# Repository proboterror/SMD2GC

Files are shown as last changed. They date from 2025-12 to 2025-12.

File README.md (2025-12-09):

# Sega Mega Drive to GameCube controller adapter

Also supports Xbox controllers (Xbox 360 / One / Series) and standard USB HID gamepads (with layout similar to PS4 DualShock 4) with USB Type-C OTG adapter.

USB gamepads support can be limited because of GameCube controller port does not provide sufficient +5V power (PS5 DualSense not working).

Bluetooth dongles are not supported unless they emulate standard USB HID device.

DualShock 3 / DualShock 4 / Xbox One / Series controllers are recommended.

Tested with USB controlers:

|Model|State|
|-----|-----|
|Xbox 360 USB|Working|
|Xbox One Model 1537|Working|
|Xbox Series Model 1914|Working|
|PS3 DualShock 3 CECHZC2R|Working|
|PS4 DualShock 4 CUH-ZCT1E|Working|
|PS5 DualSense CFI-ZCT1W|Not working<br>Unsufficient power|

## Schematics

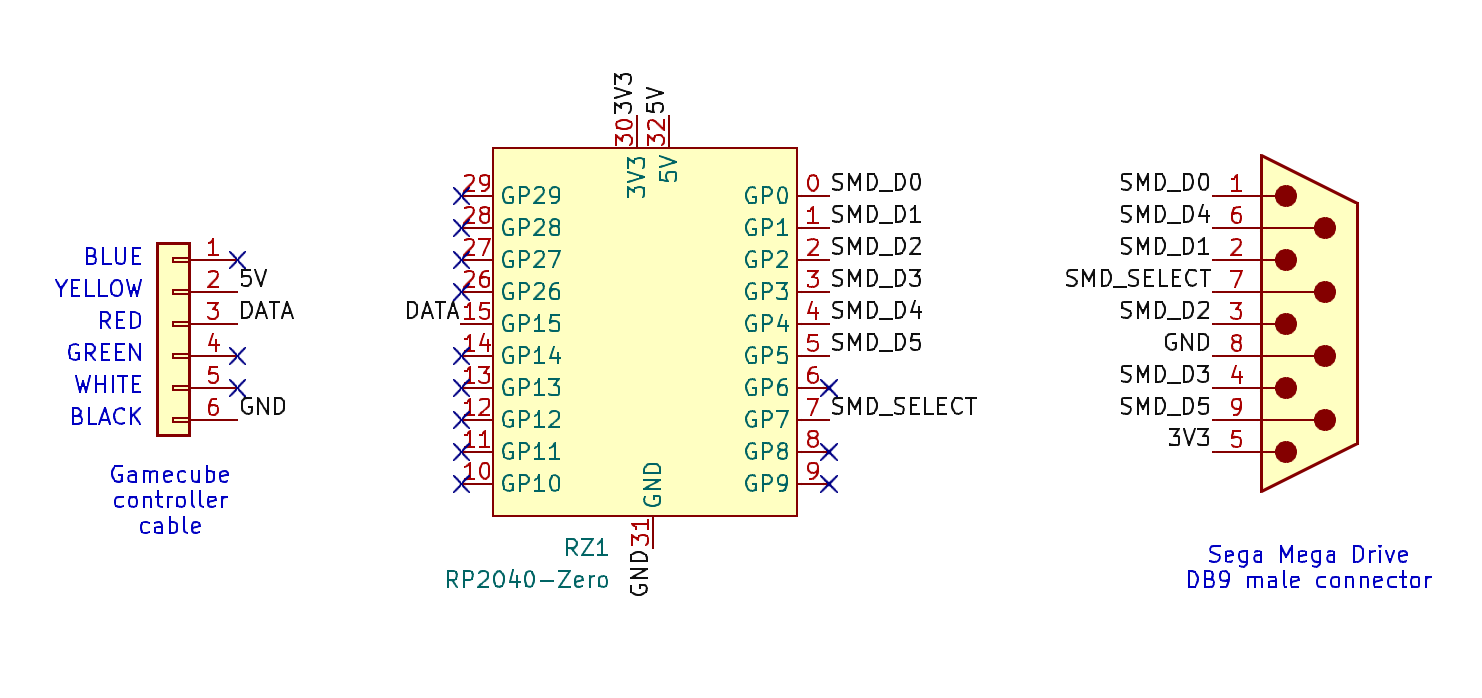
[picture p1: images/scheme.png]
Schematics


## Bill of Materials
- GameCube controller replacement cable
- WaveShare RP2040-Zero board
- DB9 Male connector
- 12 wires (approx. 60 mm each); 3 wires for USB pads only

## Buttons mapping
A/B, X/Y buttons mapping for USB gamepads matches Xbox controllers layout (reverse SNES A/B, X/Y).

### Sega Mega Drive 6-button pad
src/main.cpp:
```
gc.a = smd.a;
gc.b = smd.b;
gc.x = smd.x;
gc.y = smd.y;

gc.l = smd.z;
gc.r = smd.c;

gc.start = smd.start;

gc.dLeft = smd.left;
gc.dRight = smd.right
gc.dDown = smd.down
gc.dUp = smd.up
gc.z = smd.mode
```
### Xbox controllers
src/main.c:
```
gc.a = (buttons & XINPUT_GAMEPAD_A);
gc.b = (buttons & XINPUT_GAMEPAD_B);
gc.x = (buttons & XINPUT_GAMEPAD_X);
gc.y = (buttons & XINPUT_GAMEPAD_Y);

gc.start = (buttons & (XINPUT_GAMEPAD_START | XINPUT_GAMEPAD_GUIDE));

gc.dLeft = (buttons & XINPUT_GAMEPAD_DPAD_LEFT);
gc.dRight = (buttons & XINPUT_GAMEPAD_DPAD_RIGHT);
gc.dDown = (buttons & XINPUT_GAMEPAD_DPAD_DOWN);
gc.dUp = (buttons & XINPUT_GAMEPAD_DPAD_UP);

const uint8_t TRIGGER_CLICK_TRESHOLD = 32;
gc.l = pad->bLeftTrigger > TRIGGER_CLICK_TRESHOLD
gc.r = pad->bRightTrigger > TRIGGER_CLICK_TRESHOLD;

gc.z = (buttons & XINPUT_GAMEPAD_RIGHT_SHOULDER);

gc.xStick = int16_to_u8_biased(pad->sThumbLX);
gc.yStick = int16_to_u8_biased(pad->sThumbLY);

gc.cxStick = int16_to_u8_biased(pad->sThumbRX);
gc.cyStick = int16_to_u8_biased(pad->sThumbRY);

gc.analogL = pad->bLeftTrigger;
gc.analogR = pad->bRightTrigger;
```

### Standard USB HID controllers (DualShock 4)
src/hid_gamecube_mapping.cpp:
```
REPORT_USAGE_PAGE_BUTTON, 1, MAP_GAMECUBE_BUTTON_X // Square -> X
REPORT_USAGE_PAGE_BUTTON, 2, MAP_GAMECUBE_BUTTON_A // Cross -> A
REPORT_USAGE_PAGE_BUTTON, 3, MAP_GAMECUBE_BUTTON_B // Circle -> B
REPORT_USAGE_PAGE_BUTTON, 4, MAP_GAMECUBE_BUTTON_Y // Triangle -> Y

REPORT_USAGE_PAGE_BUTTON, 6, MAP_GAMECUBE_BUTTON_Z // R1

// Note: DualShock S4 generates press event starting from minimum force,
// GameCube controller generates L/R clicks after maximum force to analog L/R axes applied.
// Can be replaced with mapping analog Rx/Ry axis with MAP_TYPE_THRESHOLD_ABOVE 192 (75%) to GameCube L/R.
REPORT_USAGE_PAGE_BUTTON, 7, MAP_GAMECUBE_BUTTON_L // L2 Digital
REPORT_USAGE_PAGE_BUTTON, 8, MAP_GAMECUBE_BUTTON_R // R2 Digital

REPORT_USAGE_PAGE_BUTTON, 10, MAP_GAMECUBE_BUTTON_START // Options -> Start

// Left analog
REPORT_USAGE_X, MAP_GAMECUBE_AXIS_X // LX
REPORT_USAGE_Y, MAP_GAMECUBE_AXIS_Y // LY, inverted
// Right analog
REPORT_USAGE_Z, MAP_GAMECUBE_AXIS_CX // RX 
REPORT_USAGE_Rz, MAP_GAMECUBE_AXIS_CY // RY, inverted
// Analog left/right triggers
REPORT_USAGE_Rx, MAP_GAMECUBE_AXIS_L // LT / R2
REPORT_USAGE_Ry, MAP_GAMECUBE_AXIS_R // RT / R2

// POV/HAT switch (also D-PAD in most cases)
// 0 on hat switch, just press up
MAP_GAMECUBE_U, HID_GAMEPAD_HAT_UP
// 1 on hat switch, press up and right
HID_GAMEPAD_HAT_UP_RIGHT, MAP_GAMECUBE_U
HID_GAMEPAD_HAT_UP_RIGHT, MAP_GAMECUBE_R
// 2 on hat switch, press right
HID_GAMEPAD_HAT_RIGHT, MAP_GAMECUBE_R
// 3 on hat, press right and down
HID_GAMEPAD_HAT_DOWN_RIGHT, MAP_GAMECUBE_R
HID_GAMEPAD_HAT_DOWN_RIGHT, MAP_GAMECUBE_D
// 4 on hat, press down
HID_GAMEPAD_HAT_DOWN, MAP_GAMECUBE_D
// 5 on hat, press down and left
HID_GAMEPAD_HAT_DOWN_LEFT, MAP_GAMECUBE_D
HID_GAMEPAD_HAT_DOWN_LEFT, MAP_GAMECUBE_L
// 6 on hat, press left
HID_GAMEPAD_HAT_LEFT, MAP_GAMECUBE_L
// 7 on hat, press left and up
HID_GAMEPAD_HAT_UP_LEFT, MAP_GAMECUBE_L
HID_GAMEPAD_HAT_UP_LEFT, MAP_GAMECUBE_U

// Rarely used
REPORT_USAGE_DPAD_UP, MAP_GAMECUBE_U
REPORT_USAGE_DPAD_DOWN, MAP_GAMECUBE_D
REPORT_USAGE_DPAD_RIGHT, MAP_GAMECUBE_R
REPORT_USAGE_DPAD_LEFT, MAP_GAMECUBE_L

PS4 DualShock 4 / PS5 DualSense used as reference for buttons IDs:
Button 0x01 - Square button
Button 0x02 - Cross button
Button 0x03 - Circle button
Button 0x04 - Triangle button
Button 0x05 - L1 button
Button 0x06 - R1 button
Button 0x07 - L2 button
Button 0x08 - R2 button
Button 0x09 - Share button
Button 0x0A - Options button
Button 0x0B - L3 button
Button 0x0C - R3 button
Button 0x0D - PS button
Button 0x0E - Touchpad button
```

### DualShock 3
```
gc.a = ps3->button_cross;
gc.b = ps3->button_circle;
gc.x = ps3->button_square;
gc.y = ps3->button_triangle;
gc.start = ps3->button_start;

gc.dLeft = ps3->dpad_left;
gc.dRight = ps3->dpad_right;
gc.dDown = ps3->dpad_down;
gc.dUp = ps3->dpad_up;

const uint8_t TRIGGER_CLICK_TRESHOLD = 32;
gc.l = ps3->trigger_l2_analog > TRIGGER_CLICK_TRESHOLD;
gc.r = ps3->trigger_r2_analog > TRIGGER_CLICK_TRESHOLD;

gc.z = ps3->trigger_r1;

gc.xStick = ps3->joy_left_x;
gc.yStick = UINT8_MAX - ps3->joy_left_y;
gc.cxStick = ps3->joy_right_x;
gc.cyStick = UINT8_MAX - ps3->joy_right_y;
gc.analogL = ps3->trigger_l2_analog;
gc.analogR = ps3->trigger_r2_analog;
```

## Input lag / latency
For Sega Mega Drive 6 buttons pad delay mostly defined by GameCube controller JoyBus speed if queried once per frame:<br>
3 bytes console request + 8 bytes response @250kbps: protocol delay ~0.35 ms.

USB pads are reports its state at fixed rate, mostly 125Hz (8 ms latency).<br>
DualShock 4 has a default wired polling rate 250Hz (4ms latency)<br>
Xbox Series Controller Model 1914: default USB poll rate 125Hz (8 ms latency)

## How to flash firmware
- Connect RP2040-Zero to PC
- Press BOOT and then RESET, new drive will appear
- Drop SMD2GC.uf2 from Releases section to new drive

## How to build firmware
Checkhout git repository.
```
git submodule update --init
```
Easy way:
- Install Visual Studio Code and official Raspberry Pi Pico Visual Studio Code extension
- On "Raspberry Pi Pico Project" left tab: "Import project"
- "Configure Cmake", use toolchain installed with Raspberry Pi Pico Visual Studio Code extension
- "Compile Project"
- "Run Project (USB)". Board should be in BOOT mode.

Hard way:
- Install Raspberry Pi Pico SDK, ARM-GCC toolchain, CMake.

## Credits
- [Julien Bernard](https://github.com/JulienBernard3383279/pico-rectangle) - Joybus protocol (Gamecube controller) implementation for the Raspberry Pi Pico
- [riguetti](https://github.com/riguetti/RP2040-Zero-gamecube-controller) - unused code cleanup
- [Andrew Tait](https://github.com/rasteri/HIDman) - USB HID descriptors and reports parsing code
- [Ryzee119](https://github.com/Ryzee119/tusb_xinput) - Xbox/Xinpit controllers support module for TinyUSB library

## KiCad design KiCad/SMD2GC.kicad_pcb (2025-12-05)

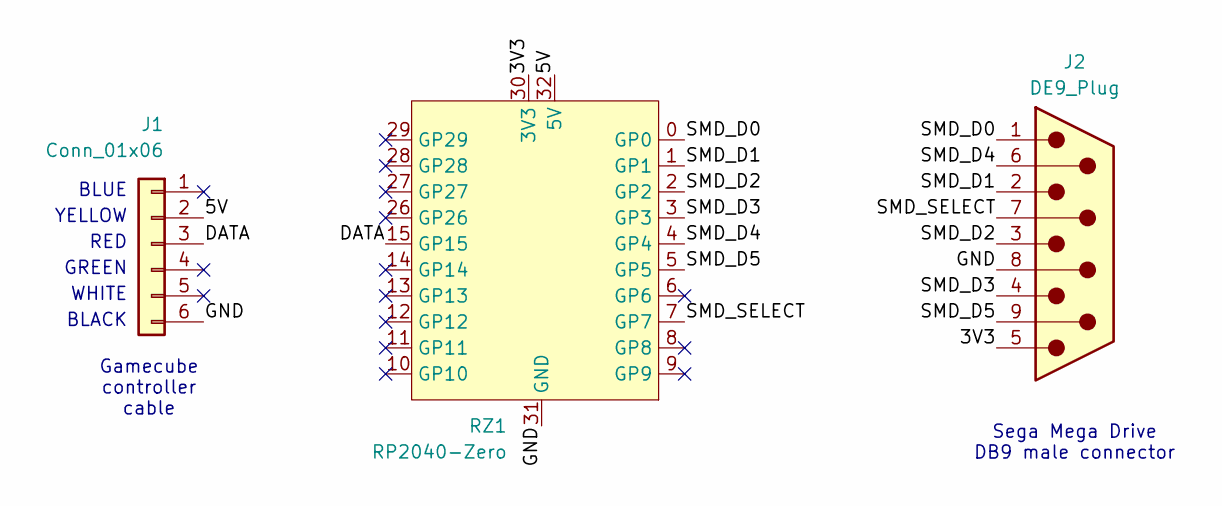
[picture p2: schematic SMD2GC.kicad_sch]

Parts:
J1: Conn_01x06; PinHeader_1x06_P2.00mm_Vertical
J2: DE9_Plug; DSUB-9_Male_Horizontal_P2.77x2.84mm_EdgePinOffset7.70mm_Hou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
RZ1: RP2040-Zero

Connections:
/3V3: J2.5, RZ1.30 (3V3)
/5V: J1.2, RZ1.32 (5V)
/DATA: J1.3, RZ1.15 (GP15)
/GND: J1.6, J2.8, RZ1.31 (GND)
/SMD_D0: J2.1, RZ1.0 (GP0)
/SMD_D1: J2.2, RZ1.1 (GP1)
/SMD_D2: J2.3, RZ1.2 (GP2)
/SMD_D3: J2.4, RZ1.3 (GP3)
/SMD_D4: J2.6, RZ1.4 (GP4)
/SMD_D5: J2.9, RZ1.5 (GP5)
/SMD_SELECT: J2.7, RZ1.7 (GP7)

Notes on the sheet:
YELLOW
WHITE
Sega Mega Drive DB9 male connector
BLUE
RED
Gamecube controller cable
BLACK
GREEN

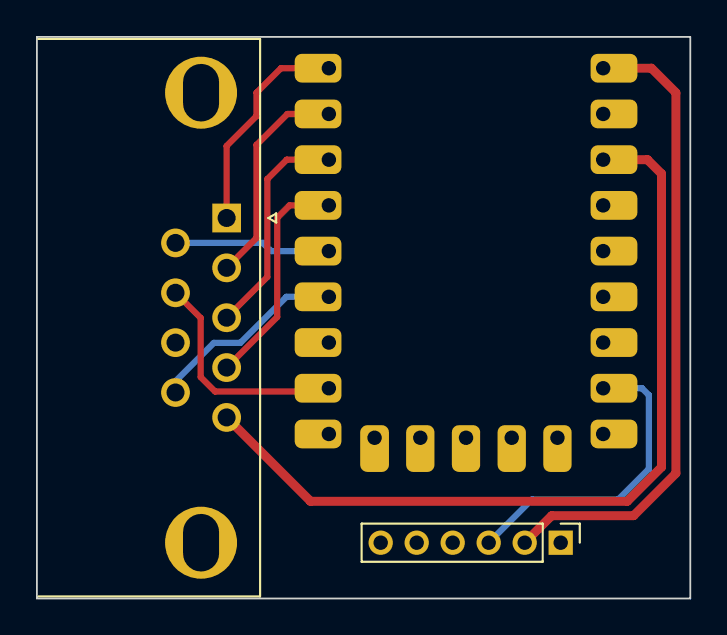
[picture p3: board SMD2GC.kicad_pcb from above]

Board: 2 copper layers, 36.3 x 31.2 mm, 3 parts (1 on the bottom side), 11 nets.

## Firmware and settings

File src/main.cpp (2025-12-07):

#include "pico/stdlib.h"
#include "pico/multicore.h"
#include "pico/sync.h"
#include "pico/stdio_uart.h"
#include "hardware/clocks.h"

#include "host/usbh.h"
#include "tusb.h"

#include "hid_parser.h"
#include "hid_gamecube_mapping.h"

#include "ps3.h"

#include "sega_mega_drive.h"
#include "communication_protocols/joybus.hpp"

// Minimal frequency required for stable USB Host support on RP2040 is 144 MHz (multiple of 48 MHz USB clock).
// GameCube JoyBus support pio program timings are for 25 MHz clock.
// JoyBus pio program clock divider set to 6 (150/6).
// 125 MHz with pio divider set to 5 working with DualShock 4, Xbox Series Model 1914 Controller; Xbox 360 controller unstable, DualSense attachment not detected (VBUS below 5V issue).
const int FREQUENCY_MHZ = 150;

const uint8_t TRIGGER_CLICK_TRESHOLD = 32;

GCReport globalGCState = defaultGcReport;
spin_lock_t* shared_data_lock = nullptr;
bool usb_gamepad_connected = false;

enum usb_hid_device_type
{
	USB_HID_DEVICE_NONE,
	USB_HID_DEVICE_STANDARD,
	USB_HID_DEVICE_DUALSHOCK3
};

usb_hid_device_type g_device_type[CFG_TUH_DEVICE_MAX] = {};

void tuh_hid_mount_cb(uint8_t dev_addr, uint8_t instance,
					  uint8_t const* desc_report, uint16_t desc_len)
{
	TU_LOG1("HID device attached\n");

	uint16_t vid, pid;
    tuh_vid_pid_get(dev_addr, &vid, &pid);

	if(ps3_usb_match(vid, pid))
	{
		if(ps3_usb_init(dev_addr, instance))
			g_device_type[dev_addr] = USB_HID_DEVICE_DUALSHOCK3;
		else
			return;
	}
	else
	{
		if (desc_report)
		{
			TU_LOG1("[HID] Using built-in descriptor (%d bytes)\n", desc_len);

			if(ParseReportDescriptor(desc_report, desc_len, hid_to_gamecube_mapping))
				g_device_type[dev_addr] = USB_HID_DEVICE_STANDARD;
			else
				return;
		}
		else
		{
			TU_LOG1("[HID] Descriptor too large (%d bytes)\n", desc_len);

			return;
		}
	}

	usb_gamepad_connected = true;

	tuh_hid_receive_report(dev_addr, instance); // Queue first report receive
}

void tuh_hid_umount_cb(uint8_t dev_addr, uint8_t instance)
{
	TU_LOG1("HID device removed\n");

	g_device_type[dev_addr] = USB_HID_DEVICE_NONE;

	usb_gamepad_connected = false;
}

GCReport g_gamepad = defaultGcReport;

static void gamepad_callback(uint32_t control_type, uint32_t value)
{
	const GamecubeMappings mapping = (GamecubeMappings)control_type;

	const char* gc_controls_names[] = {"A", "B", "X", "Y", "START", "R", "L", "D", "U", "Z", "R", "L", "AXIS_X", "AXIS_Y", "AXIS_CX", "AXIS_CY", "AXIS_L", "AXIS_R"};

	if(control_type < MAP_GAMECUBE_AXIS_X)
	{
		TU_LOG2("gamepad_callback: type=%s, value=%d\n", gc_controls_names[control_type], value);
	}

	if (mapping == MAP_GAMECUBE_BUTTON_A)
		g_gamepad.a = true;
	else if(mapping == MAP_GAMECUBE_BUTTON_B)
		g_gamepad.b = true;
	else if(mapping == MAP_GAMECUBE_BUTTON_X)
		g_gamepad.x = true;
	else if(mapping == MAP_GAMECUBE_BUTTON_Y)
		g_gamepad.y = true;
	else if(mapping == MAP_GAMECUBE_BUTTON_START)
		g_gamepad.start = true;
	else if(mapping == MAP_GAMECUBE_R)
		g_gamepad.dRight = true;
	else if(mapping == MAP_GAMECUBE_L)
		g_gamepad.dLeft = true;
	else if(mapping == MAP_GAMECUBE_D)
		g_gamepad.dDown = true;
	else if(mapping == MAP_GAMECUBE_U)
		g_gamepad.dUp = true;
	else if(mapping == MAP_GAMECUBE_BUTTON_Z)
		g_gamepad.z = true;
	else if(mapping == MAP_GAMECUBE_BUTTON_R)
		g_gamepad.r = true;
	else if(mapping == MAP_GAMECUBE_BUTTON_L)
		g_gamepad.l = true;
	else if(mapping == MAP_GAMECUBE_AXIS_X)
		g_gamepad.xStick = value;
	else if(mapping == MAP_GAMECUBE_AXIS_Y)
		g_gamepad.yStick = UINT8_MAX - value;
	else if(mapping == MAP_GAMECUBE_AXIS_CX)
		g_gamepad.cxStick = value;
	else if(mapping == MAP_GAMECUBE_AXIS_CY)
		g_gamepad.cyStick = UINT8_MAX - value;
	else if(mapping == MAP_GAMECUBE_AXIS_L) // Note: DualShock 4 / DualSence also maps to L2/R2 triggers press
		g_gamepad.analogL = value;
	else if(mapping == MAP_GAMECUBE_AXIS_R)
		g_gamepad.analogR = value;
}

void tuh_hid_report_received_cb(uint8_t dev_addr,
								uint8_t instance,
								uint8_t const* report,
								uint16_t len)
{
	if(g_device_type[dev_addr] == USB_HID_DEVICE_DUALSHOCK3)
	{
		ps3_hid_report_t* ps3 = ps3_usb_parse_report(report, len);

		if(ps3)
		{
			g_gamepad = defaultGcReport;

			g_gamepad.a = ps3->button_cross;
			g_gamepad.b = ps3->button_circle;
			g_gamepad.x = ps3->button_square;
			g_gamepad.y = ps3->button_triangle;
			g_gamepad.start = ps3->button_start;
			
			g_gamepad.dLeft = ps3->dpad_left;
			g_gamepad.dRight = ps3->dpad_right;
			g_gamepad.dDown = ps3->dpad_down;
			g_gamepad.dUp = ps3->dpad_up;

			g_gamepad.l = ps3->trigger_l2_analog > TRIGGER_CLICK_TRESHOLD;
			g_gamepad.r = ps3->trigger_r2_analog > TRIGGER_CLICK_TRESHOLD;	
			//g_gamepad.l = ps3->trigger_l1;
			//g_gamepad.r = ps3->trigger_r1;
			g_gamepad.z = ps3->trigger_r1;
			
			g_gamepad.xStick = ps3->joy_left_x;
			g_gamepad.yStick = UINT8_MAX - ps3->joy_left_y;
			g_gamepad.cxStick = ps3->joy_right_x;
			g_gamepad.cyStick = UINT8_MAX - ps3->joy_right_y;
			g_gamepad.analogL = ps3->trigger_l2_analog;
			g_gamepad.analogR = ps3->trigger_r2_analog;
		}
	}
	else if (g_device_type[dev_addr] = USB_HID_DEVICE_STANDARD)
	{
		g_gamepad = defaultGcReport;
	
		ParseReport(report, len, gamepad_callback);
	}

	spin_lock_unsafe_blocking(shared_data_lock);
	globalGCState = g_gamepad;
	spin_unlock_unsafe(shared_data_lock);

	// Queue the next receive immediately to maintain polling
	tuh_hid_receive_report(dev_addr, instance);
}

// Callback invoked when a device is mounted
void tuh_mount_cb(uint8_t dev_addr)
{
	printf("A device with address %d was mounted\r\n", dev_addr);
}

// Callback invoked when a device is unmounted
void tuh_umount_cb(uint8_t dev_addr)
{
	printf("A device with address %d was unmounted\r\n", dev_addr);
}

GCReport getControllerState()
{
	if(usb_gamepad_connected)
	{
		spin_lock_unsafe_blocking(shared_data_lock);
		GCReport report = globalGCState;
		spin_unlock_unsafe(shared_data_lock);
		return report;
	}
	else
	{
		const smd_state_t smd = getSegaMegaDriveReport();

		GCReport gcReport = defaultGcReport;

		gcReport.a = smd.a;
		gcReport.b = smd.b;
		gcReport.x = smd.x;
		gcReport.y = smd.y;
		gcReport.l = smd.z;
		gcReport.r = smd.c;

		gcReport.start = smd.start;

		gcReport.dLeft = smd.left;
		gcReport.dRight = smd.right;
		gcReport.dDown = smd.down;
		gcReport.dUp = smd.up;
		gcReport.z = smd.mode;

		return gcReport;
	}
}

#include "xinput_host.h"

//Since https://github.com/hathach/tinyusb/pull/2222, we can add in custom vendor drivers easily
usbh_class_driver_t const* usbh_app_driver_get_cb(uint8_t* driver_count)
{
	*driver_count = 1;

	return &usbh_xinput_driver;
}

static inline uint8_t int16_to_u8_biased(int16_t x)
{
	return (uint8_t)((uint32_t)(x + 32768) >> 8);
}

void tuh_xinput_report_received_cb(uint8_t dev_addr, uint8_t instance, xinputh_interface_t const* xid_itf, uint16_t len)
{
	const xinput_gamepad_t *pad = &xid_itf->pad;
	const char* type_str;

	if (xid_itf->last_xfer_result == XFER_RESULT_SUCCESS)
	{
		switch (xid_itf->type)
		{
			case 1: type_str = "Xbox One";          break;
			case 2: type_str = "Xbox 360 Wireless"; break;
			case 3: type_str = "Xbox 360 Wired";    break;
			case 4: type_str = "Xbox OG";           break;
			default: type_str = "Unknown";
		}

		if (xid_itf->connected && xid_itf->new_pad_data)
		{
			TU_LOG2("[%02x, %02x], Type: %s, Buttons %04x, LT: %02x RT: %02x, LX: %d, LY: %d, RX: %d, RY: %d\n",
				dev_addr, instance, type_str, pad->wButtons, pad->bLeftTrigger, pad->bRightTrigger, pad->sThumbLX, pad->sThumbLY, pad->sThumbRX, pad->sThumbRY);

			GCReport gc = defaultGcReport;
			const uint16_t buttons = pad->wButtons;

			gc.a = (buttons & XINPUT_GAMEPAD_A) != 0;
			gc.b = (buttons & XINPUT_GAMEPAD_B) != 0;
			gc.x = (buttons & XINPUT_GAMEPAD_X) != 0;
			gc.y = (buttons & XINPUT_GAMEPAD_Y) != 0;
			gc.start = (buttons & (XINPUT_GAMEPAD_START | XINPUT_GAMEPAD_GUIDE)) != 0;
			
			gc.dLeft = (buttons & XINPUT_GAMEPAD_DPAD_LEFT) != 0;
			gc.dRight = (buttons & XINPUT_GAMEPAD_DPAD_RIGHT) != 0;
			gc.dDown = (buttons & XINPUT_GAMEPAD_DPAD_DOWN) != 0;
			gc.dUp = (buttons & XINPUT_GAMEPAD_DPAD_UP) != 0;

			gc.l = pad->bLeftTrigger > TRIGGER_CLICK_TRESHOLD;
			gc.r = pad->bRightTrigger > TRIGGER_CLICK_TRESHOLD;	
			//gc.l = (buttons & XINPUT_GAMEPAD_LEFT_SHOULDER) != 0;
			//gc.r = (buttons & XINPUT_GAMEPAD_RIGHT_SHOULDER) != 0;
			gc.z = (buttons & XINPUT_GAMEPAD_RIGHT_SHOULDER) != 0;
			
			gc.xStick = int16_to_u8_biased(pad->sThumbLX);
			gc.yStick = int16_to_u8_biased(pad->sThumbLY);
			gc.cxStick = int16_to_u8_biased(pad->sThumbRX);
			gc.cyStick = int16_to_u8_biased(pad->sThumbRY);
			gc.analogL = pad->bLeftTrigger;
			gc.analogR = pad->bRightTrigger;

			spin_lock_unsafe_blocking(shared_data_lock);
			globalGCState = gc;
			spin_unlock_unsafe(shared_data_lock);
		}
	}

	tuh_xinput_receive_report(dev_addr, instance);
}

void tuh_xinput_mount_cb(uint8_t dev_addr, uint8_t instance, const xinputh_interface_t *xinput_itf)
{
	TU_LOG1("XInput Mounted %02x %d\n", dev_addr, instance);
	// If this is a Xbox 360 Wireless controller we need to wait for a connection packet
	// on the in pipe before setting LEDs etc. So just start getting data until a controller is connected.
	if (xinput_itf->type == XBOX360_WIRELESS && xinput_itf->connected == false)
	{
		tuh_xinput_receive_report(dev_addr, instance);

		return;
	}

	tuh_xinput_set_led(dev_addr, instance, 0, true);
	tuh_xinput_set_led(dev_addr, instance, 1, true);
	tuh_xinput_set_rumble(dev_addr, instance, 0, 0, true);
	tuh_xinput_receive_report(dev_addr, instance);

	usb_gamepad_connected = true;
}

void tuh_xinput_umount_cb(uint8_t dev_addr, uint8_t instance)
{
	TU_LOG1("XInput Unmounted %02x %d\n", dev_addr, instance);

	usb_gamepad_connected = false;
}

void core1_main(void)
{
	if (!tuh_init(BOARD_TUH_RHPORT))
	{
		printf("Failed to initialize TinyUSB Host\n");
		return;
	}

	while(true)
	{
		tuh_task();
		tight_loop_contents(); // sleep_us(100);
	}
}

int main()
{
	set_sys_clock_khz(1000 * FREQUENCY_MHZ, true);

	stdio_uart_init();
	stdio_init_all();

	printf("SMD2GC Sega Mega Drive / USB HID to GameCube adapter\nhttps://github.com/proboterror/SMD2GC\n");

	uint lock_num = spin_lock_claim_unused(true);  // Low-level: returns uint ID; panic if none free
	if (lock_num == (uint)-1) // No free locks (rare, but check)
	{
		panic("No free spinlocks available!");
	}
	shared_data_lock = spin_lock_init(lock_num);   // High-level: convert uint to spin_lock_t*

	multicore_launch_core1(core1_main);

	initSegaMegaDrive();

	CommunicationProtocols::Joybus::enterMode(
			[]() {
				return getControllerState();
			});
}

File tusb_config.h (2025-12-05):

#ifndef _TUSB_CONFIG_H_
#define _TUSB_CONFIG_H_

//--------------------------------------------------------------------
// COMMON CONFIGURATION
//--------------------------------------------------------------------
// Set the controller mode to Host for the RP2040 USB port (Port 0)
#define CFG_TUSB_RHPORT0_MODE   OPT_MODE_HOST 
#define CFG_TUSB_OS             OPT_OS_PICO

// Debug level (0-3). 0 = no debug output; Level 2: Full control transfer logs (descriptor gets, errors)
//#define CFG_TUSB_DEBUG          0
// Host-specific: Pipe opens, enumeration steps
//#define CFG_TUH_DEBUG           0

//--------------------------------------------------------------------
// HOST CONFIGURATION
//--------------------------------------------------------------------
#define CFG_TUH_DEVICE_MAX          2 // At least 2, 4 is safe
#define CFG_TUH_HUB                 1 // Support hubs (recommended)

// Size of the enumeration buffer (typically 256 bytes is enough)
#define CFG_TUH_ENUMERATION_BUFSIZE 512

//--------------------------------------------------------------------
// CLASS DRIVERS
//--------------------------------------------------------------------
#define CFG_TUH_HID 1
#define CFG_TUH_XINPUT 1

// HID report descriptor buffer
#define CFG_TUH_HID_DESC_BUFSIZE  1024

#endif

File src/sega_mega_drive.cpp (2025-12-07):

#include <array>

#include "pico/stdlib.h"

#include "sega_mega_drive.h"

/*
	GPIO pins connection to Sega Mega Drive Controller DB9 Male connector:
	Signal   D0 D1 D2 D3 D4 D5 SEL GND VCC
	DB9 pin  1  2  3  4  6  9  7   8   5
	GPIO pin 0  1  2  3  4  5  7   GND 3V3
*/
constexpr uint8_t SMD_DATA_PIN0 = 0;
constexpr uint8_t SMD_DATA_PIN1 = 1;
constexpr uint8_t SMD_DATA_PIN2 = 2;
constexpr uint8_t SMD_DATA_PIN3 = 3;
constexpr uint8_t SMD_DATA_PIN4 = 4;
constexpr uint8_t SMD_DATA_PIN5 = 5;
constexpr uint8_t SMD_SELECT_PIN = 7;

smd_state_t smd;

void initSegaMegaDrive()
{
	std::array<uint8_t,6> smd_gpio = 
	{
		SMD_DATA_PIN0,
		SMD_DATA_PIN1,
		SMD_DATA_PIN2,
		SMD_DATA_PIN3,
		SMD_DATA_PIN4,
		SMD_DATA_PIN5
	}; // SMD data pins

	for (uint8_t pin : smd_gpio)
	{
		gpio_init(pin);
		gpio_set_dir(pin, GPIO_IN);
		gpio_pull_up(pin); // For correct controller presence detection.
	}

	// SMD SEl pin
	gpio_init(SMD_SELECT_PIN);
	gpio_set_dir(SMD_SELECT_PIN, GPIO_OUT);
	gpio_disable_pulls(SMD_SELECT_PIN);
}

/*
	References:
	https://www.raspberryfield.life/2019/03/25/sega-mega-drive-genesis-6-button-xyz-controller/
	https://segaretro.org/Six_Button_Control_Pad_(Mega_Drive)
	https://segaretro.org/File:Genesis_Software_Manual.pdf
	Questionable:
	https://segaretro.org/Sega_Mega_Drive/Control_pad_inputs
*/
smd_state_t getSegaMegaDriveReport()
{
	static uint32_t last_update_time = 0;
	uint32_t current_time = time_us_32();

	constexpr uint32_t SMD_RESET_DELAY = 3*1000; // Must be >= 3 to give 6-button controller time to reset

	// check last read time; return last result if < 3 ms passed (required for 6 buttons pads to reset state)
	if((current_time - last_update_time) >= SMD_RESET_DELAY)
	{
		last_update_time = current_time;
/*
    Cycle  SEL out D5 in  D4 in  D3 in  D2 in  D1 in  D0 in
    0      HI      C      B      Right  Left   Down   Up      (Read B, C and directions in this cycle)
    1      LO      Start  A      0      0      Down   Up      (Check connected and read Start and A in this cycle)
    2      HI      C      B      Right  Left   Down   Up
    3      LO      Start  A      0      0      Down   Up
    4      HI      C      B      Right  Left   Down   Up
    5      LO      Start  A      0      0      0      0       (Check for six button controller in this cycle (D0 and D1 == LOW))
    6      HI      C      B      Mode   X      Y      Z       (Read X,Y,Z and Mode in this cycle)
    7      LO      ---    ---    ---    ---    ---    ---     (Ignored)
*/
		size_t constexpr CYCLES_COUNT = 8; // 8 iterations for read controller state.

		uint8_t smd_data[CYCLES_COUNT] = {};

		bool select = true;
		gpio_put(SMD_SELECT_PIN, select);

		for (size_t i = 0; i < CYCLES_COUNT; i++)
		{
/*
	Genesis Software Manual (C) 1989 Sega of Japan:
	Genesis Technical Bulletin #27 January 24, 1994:
	1. Warning regarding control pad data reads
	For both the 3 and 6 button pads, the pad data is determined 2usec after TH is modified.
	Therefore, as shown in the sample below, read data from the pad 2usec (4 nop's) after TH is modified.
	Joypad Reads
	Pad data from the 3 and 6 button controllers are read 2usec after TH is modified.
	The wait is necessary because the data in the chip needs time to stabilize after TH is modified.
	If data is read without this wait, there is no guarantee that the data will be correct.
	Moreover, the 2usec time is equivalent to 4 nop, including the 68000's prefetch.
*/
			sleep_us(2); // Short delay to stabilise outputs in controller.

			smd_data[i] = gpio_get(SMD_DATA_PIN0)
						| gpio_get(SMD_DATA_PIN1) << 1
						| gpio_get(SMD_DATA_PIN2) << 2
						| gpio_get(SMD_DATA_PIN3) << 3
						| gpio_get(SMD_DATA_PIN4) << 4
						| gpio_get(SMD_DATA_PIN5) << 5;

			select = !select;
			gpio_put(SMD_SELECT_PIN, select);
		}

		smd.connected = !(smd_data[1] & 0b001100);

		if (smd.connected)
		{
			// Fixed: 6-buttons controller detection:
			smd.six_buttons =  ((smd_data[5] & 0b011) == 0);

			smd.a = !!(~smd_data[1] & 0b010000);
			smd.b = !!(~smd_data[0] & 0b010000);
			smd.c = !!(~smd_data[0] & 0b100000);
			smd.x = !!(smd.six_buttons && (~smd_data[6] & 0b000100));
			smd.y = !!(smd.six_buttons && (~smd_data[6] & 0b000010));
			smd.z = !!(smd.six_buttons && (~smd_data[6] & 0b000001));
			smd.up = !!(~smd_data[0] & 0b000001);
			smd.down = !!(~smd_data[0] & 0b000010);
			smd.left = !!(~smd_data[0] & 0b000100);
			smd.right = !!(~smd_data[0] & 0b001000);
			smd.start = !!(~smd_data[1] & 0b100000);
			smd.mode = !!(smd.six_buttons && (~smd_data[6] & 0b001000));
		}
		else
		{
			smd = {};
		}
	}

	return smd;
}

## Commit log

2025-11-23 Implement Sega Mega Drive to Gamecube / Wii controller adapter firmware. 6-buttons and 3-buttons controllers supported.
    Delete unused code.
2025-11-23 Add KiCad schematic and draft PCB. RP2040-Zero symbol and footprint source: https://github.com/proboterror/Pentagon_128_Interface_Board
    [SMD2GC.kicad_pcb, SMD2GC.kicad_sch]
2025-12-05 Add xinput USB controllers support with https://github.com/Ryzee119/tusb_xinput library. Xbox 360, Xbox One / Series controllers are supported.
    Add TinyUSB library with hardware host enabled.
    Set cores clock to 150 MHz as recommended for stable USB host support. JoyBus pio program clock divider updated to keep 25 MHz clock.
    Enable stdio uart support for USB devices debugging at pins tx/rx 8/9, 115200 baud. Disable stdio over USB.
    Sega Mega Drive controller support: pullup data gpio pins by default for correct gamepad presence detection.
    [joybus.cpp, main.cpp, sega_mega_drive.cpp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]
2025-12-05 Add USB HID gamepads support. HID to GameCube mapping for PS4 DualShock 4 / PS4 DualSense layout.
    Added HID report descriptors / reports parsing / mapping library for HID gamepad / keyboad / mouse, based on https://github.com/rasteri/HIDman
    Add library unit tests and sample data, targeting Visual Studio and Windows platform (src/CMakeLists.txt).
    Test data source: own dumps if not specified.
    Tested with hardware (WaveShare RP2040-Zero with Wii GameCube controller port, rumble +5V for board / USB VBUS power):
    PS4 DualShock 4 (CUH-ZCT1E): working without issues.
    PS5 DualSense (CFI-ZCT1W): not detected, insufficient power. Working with external +5V power.
    [hid_dumps.h]
2025-12-05 Update schematic for USB VBUS +5V power from GameCube rumble power.
    [SMD2GC.kicad_pcb, SMD2GC.kicad_sch]
2025-12-06 Invert right/left Y axes for HID gamepads (DualShock 4).
    [main.cpp]
2025-12-06 PS3 DualShock 3 custom driver implemented.
    Invert analog Y axes for HID gamepads (checked with DualShock 4).
    [main.cpp]
2025-12-06 More correct report parsing error handling: - Always queue new report request - Parse HID reports only for standard HID devices with successfully parsed report descriptors
    [main.cpp]
2025-12-07 Sync DualShock / DualSense controllers A/B, X/Y buttons mapping with Xinput gamepads layout (reverse SNES A/B, X,Y).
    [main.cpp]
